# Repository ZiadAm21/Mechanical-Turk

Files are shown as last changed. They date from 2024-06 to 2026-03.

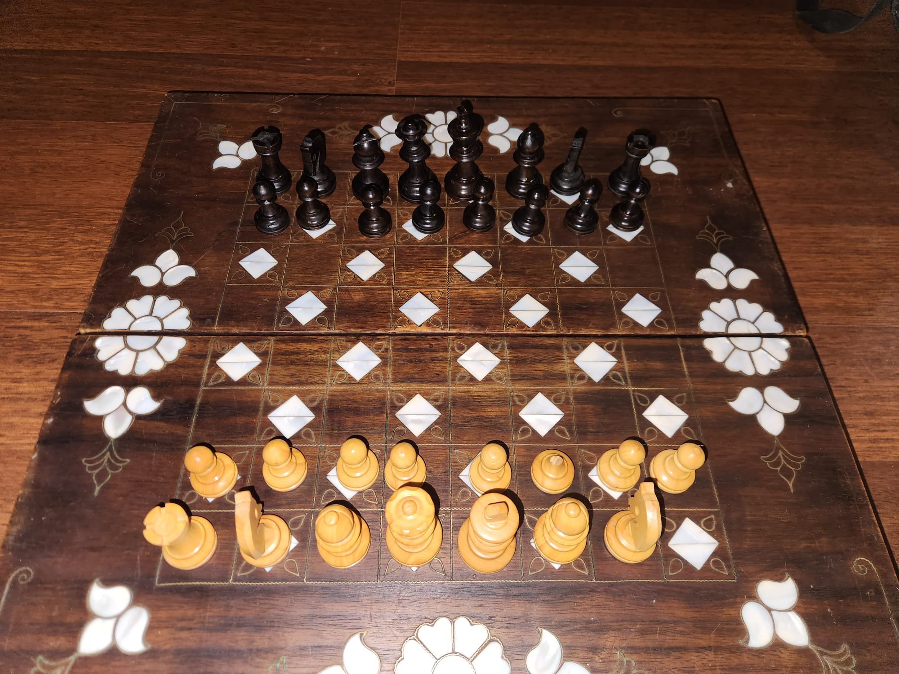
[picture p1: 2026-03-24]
Server/AI-Model/TestChessboard.jpeg

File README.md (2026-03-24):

img width="771" alt="PCB-Layout" src="https://github.com/ZiadAm21/Mechanical-Turk/assets/85026466/294146c9-6c39-458a-bf5e-eeac2324a76a"
img width="1029" alt="PCB-3D" src="https://github.com/ZiadAm21/Mechanical-Turk/assets/85026466/c324dfcb-7858-4109-8abc-ef0bd6ab6ac7"




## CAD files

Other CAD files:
AutoCAD-3DModel/Chessboard3D.dwg

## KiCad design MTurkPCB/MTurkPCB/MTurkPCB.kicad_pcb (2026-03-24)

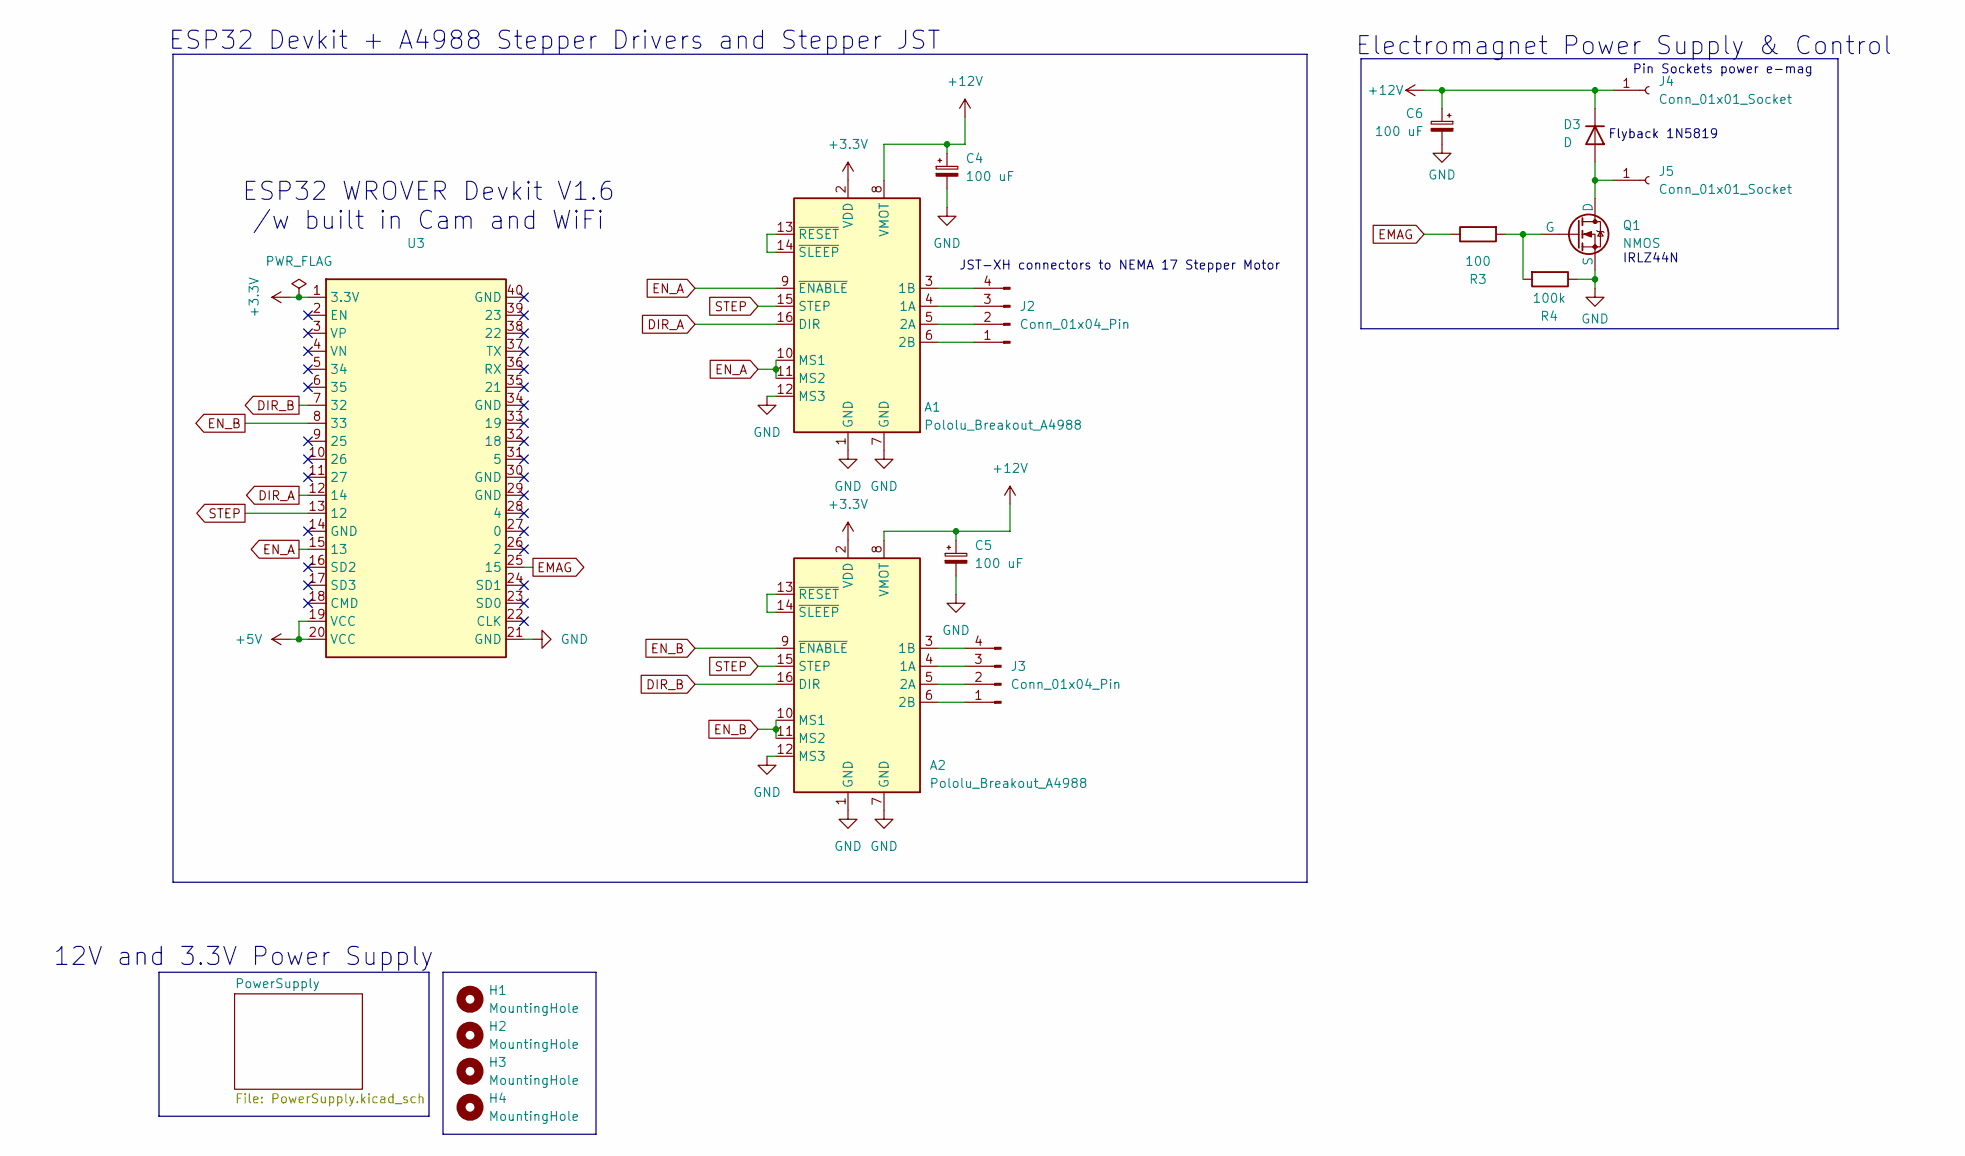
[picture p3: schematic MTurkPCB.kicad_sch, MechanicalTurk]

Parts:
A1, A2: Pololu_Breakout_A4988; Pololu_Breakout-16_15.2x20.3mm
C4, C5: 100 uF; C_0603_1608Metric
C6: 100 uF; C_0805_2012Metric_Pad1.18x1.45mm_HandSolder
D3: D; D_DO-41_SOD81_P10.16mm_Horizontal
H1, H2, H3, H4: MountingHole; MountingHole_2.2mm_M2
J2, J3: Conn_01x04_Pin; JST_XH_B4B-XH-A_1x04_P2.50mm_Vertical
J4, J5: Conn_01x01_Socket; PinSocket_1x01_P1.27mm_Vertical
Q1: NMOS; TO-220-3_Vertical
R3: 100; R_0805_2012Metric_Pad1.20x1.40mm_HandSolder
R4: 100k; R_0805_2012Metric_Pad1.20x1.40mm_HandSolder
U3: ESP32 WROVER DevKit V1.6

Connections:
+3.3V: A1.2 (VDD), A2.2 (VDD), U3.1 (3.3V)
+5V: U3.19 (VCC), U3.20 (VCC); also elsewhere on the board
+12V: A1.8 (VMOT), A2.8 (VMOT), C4.1, C5.1, C6.1, D3.1 (K), J4.1; also elsewhere on the board
DIR_A: A1.16 (DIR), U3.12 (14)
DIR_B: A2.16 (DIR), U3.7 (32)
EMAG: R3.1, U3.25 (15)
EN_A: A1.9 (~ENABLE), A1.10 (MS1), A1.11 (MS2), U3.15 (13)
EN_B: A2.9 (~ENABLE), A2.10 (MS1), A2.11 (MS2), U3.8 (33)
GND: A1.1 (GND), A1.7 (GND), A1.12 (MS3), A2.1 (GND), A2.7 (GND), A2.12 (MS3), C4.2, C5.2, C6.2, Q1.3 (S), R4.1, U3.21 (GND); also elsewhere on the board
unnamed: A1.4 (1A), J2.3
unnamed: A1.3 (1B), J2.4
unnamed: A1.5 (2A), J2.2
unnamed: A1.6 (2B), J2.1
unnamed: A1.13 (~RESET), A1.14 (~SLEEP)
unnamed: A2.4 (1A), J3.3
unnamed: A2.3 (1B), J3.4
unnamed: A2.5 (2A), J3.2
unnamed: A2.6 (2B), J3.1
unnamed: A2.13 (~RESET), A2.14 (~SLEEP)
unnamed: D3.2 (A), J5.1, Q1.1 (D)
unnamed: Q1.2 (G), R3.2, R4.2
STEP: A1.15 (STEP), A2.15 (STEP), U3.13 (12)

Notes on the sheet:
ESP32 WROVER Devkit V1.6 /w built in Cam and WiFi
Flyback 1N5819
ESP32 Devkit + A4988 Stepper Drivers and Stepper JST
Electromagnet Power Supply & Control
IRLZ44N
12V and 3.3V Power Supply
Pin Sockets power e-mag
JST-XH connectors to NEMA 17 Stepper Motor

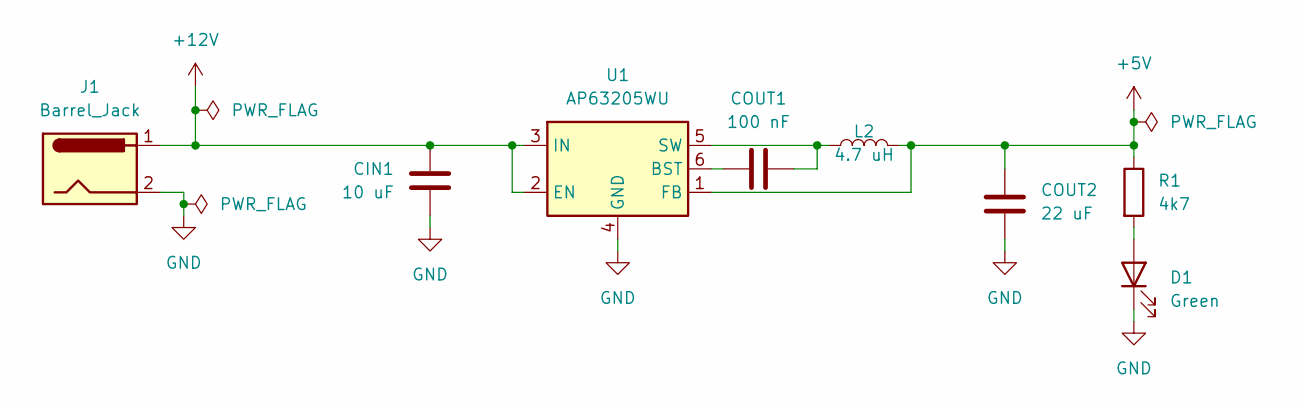
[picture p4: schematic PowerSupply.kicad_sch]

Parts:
CIN1: 10 uF; C_0603_1608Metric
COUT1: 100 nF; C_0402_1005Metric
COUT2: 22 uF; C_0805_2012Metric_Pad1.18x1.45mm_HandSolder
D1: Green; LED_0805_2012Metric
J1: Barrel_Jack; BarrelJack_GCT_DCJ200-10-A_Horizontal
L2: 4.7 uH; L_1206_3216Metric
R1: 4k7; R_0805_2012Metric
U1: AP63205WU; TSOT-23-6

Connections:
+5V: COUT2.1, L2.2, R1.1, U1.1 (FB); also elsewhere on the board
+12V: CIN1.1, J1.1, U1.2 (EN), U1.3 (IN); also elsewhere on the board
GND: CIN1.2, COUT2.2, D1.1 (K), J1.2, U1.4 (GND); also elsewhere on the board
unnamed: D1.2 (A), R1.2
unnamed: COUT1.1, U1.6 (BST)
unnamed: COUT1.2, L2.1, U1.5 (SW)

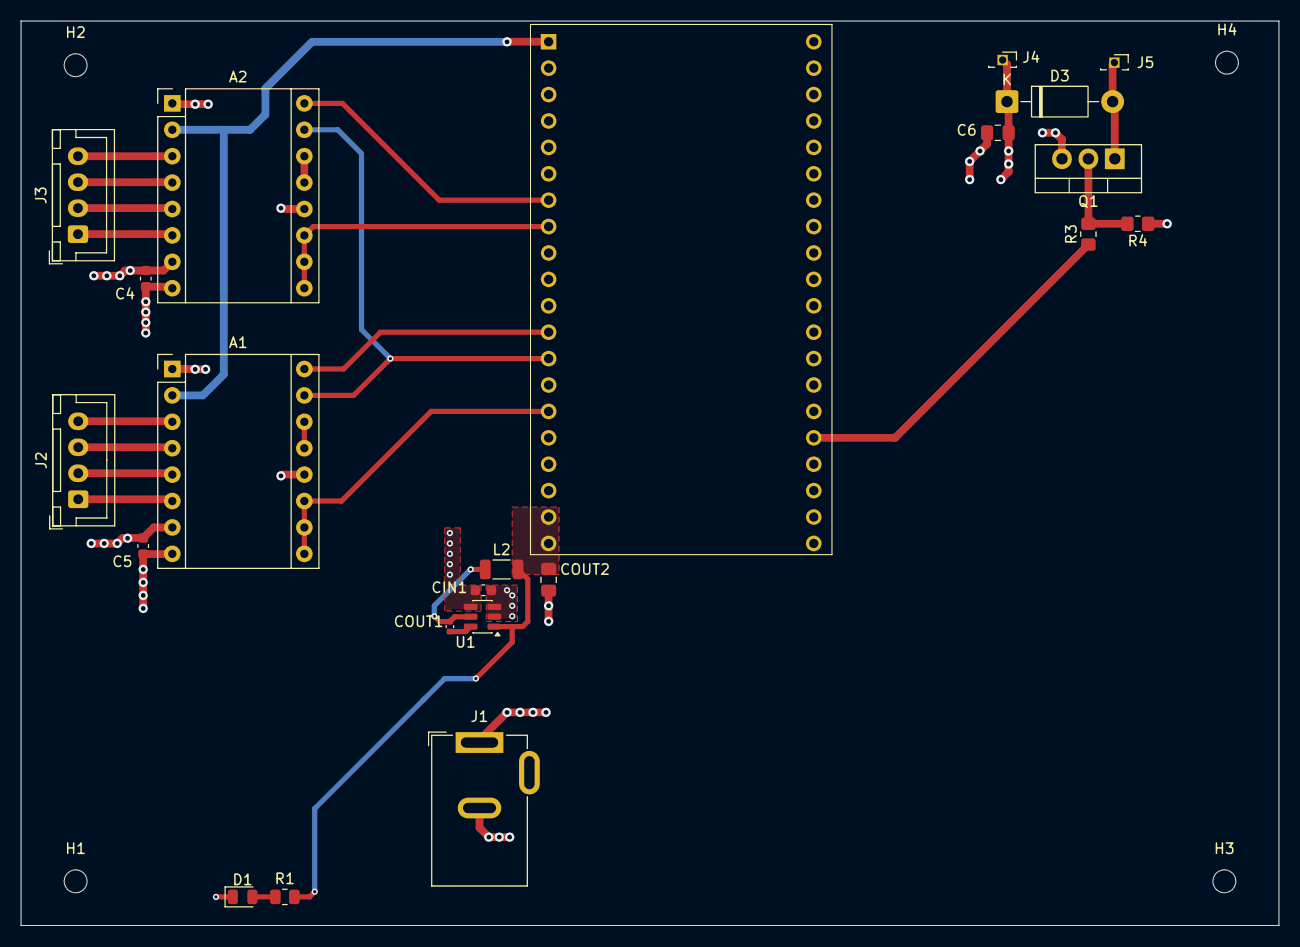
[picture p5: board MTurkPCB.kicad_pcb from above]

Board: 4 copper layers, 121.0 x 87.0 mm, 26 parts (0 on the bottom side), 25 nets.

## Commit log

2024-05-25 removing unnecessary
    [Battery+Charger.kicad_sch, Battery+ChargerCircuit.kicad_sch, OLDBattery+ChargerCircuit.kicad_sch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]
2026-03-24 Changed Schematics and ESP code
    [Chessboard3D.dwg, Controller.kicad_sch, MTurkPCB.kicad_pcb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]
